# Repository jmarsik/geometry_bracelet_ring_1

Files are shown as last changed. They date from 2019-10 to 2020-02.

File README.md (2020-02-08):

# Geometry bracelet or ring #1

OpenSCAD project that creates various customizable bracelet or ring models. You can play with a lot of parameters to archive the desired look of your bracelet (see picture).

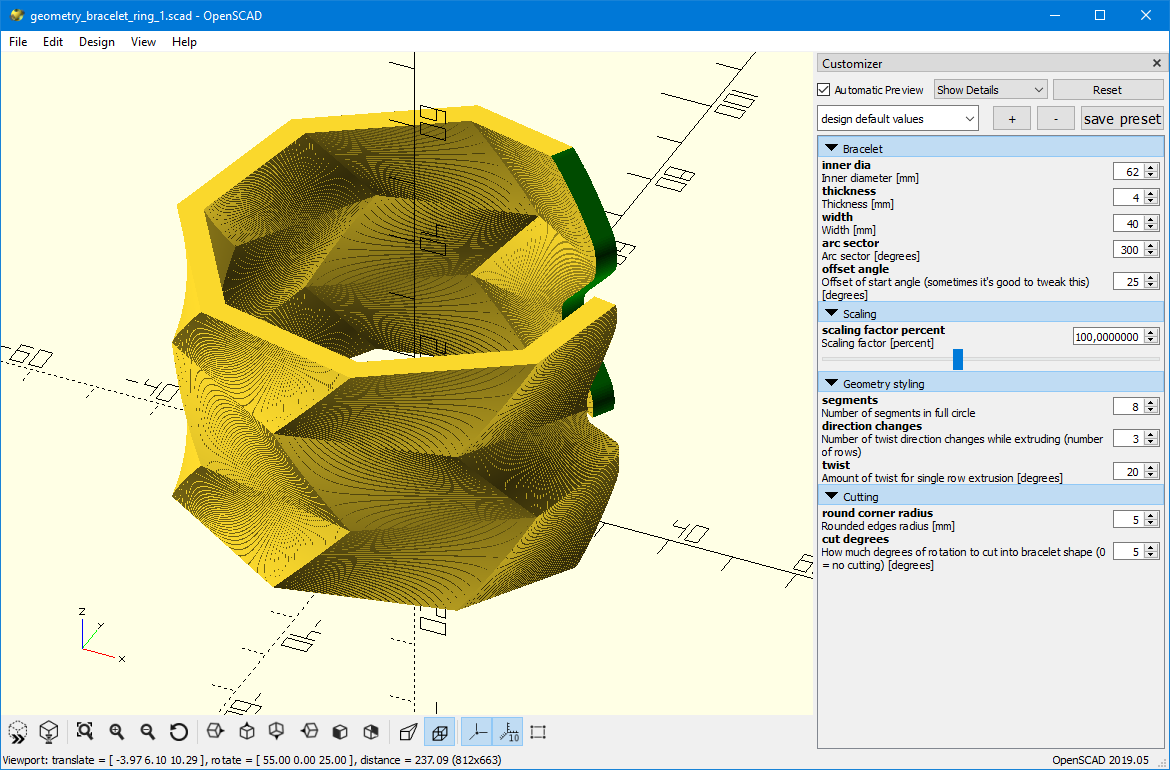
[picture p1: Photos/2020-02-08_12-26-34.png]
Bracelet customizer


There are also ready-made STL files for two bracelets and one ring, both with 8 segments, 3 directional changes and 20 degrees of twist for each directional change.

Check it out on [Thingiverse](https://www.thingiverse.com/thing:4150252) with [online customizer](https://www.thingiverse.com/apps/customizer/run?thing_id=4150252) and on [PrusaPrinters](https://www.prusaprinters.org/prints/20858-geometry-bracelet-ring)!

## Print settings

Print with some (semi)transparent PETG filament with following settings:

* without infill
* 2 perimeters
* 5 top and bottom solid layers

## Filament tips

I have tested following filaments, both bracelets and rings made from them look great and they are also __UV reactive__ (glowing in UV light)!

* [Prusament PETG Neon Green](https://amzn.to/2S9jRz5)
* [Prusament PLA Mr. Pink](https://shop.prusa3d.com/en/prusament/718-prusament-pla-ms-pink-1kg.html)

There are other UV reactive filaments listed on Amazon, some tips (not tested):

* [MG Chemicals Fluorescent Red / Hot Pink PLA](https://amzn.to/2Uy1OEe)
* [Gizmo Dorks Fluorescent Yellow PLA](https://amzn.to/39fn1Hl)
* [Gizmo Dorks Fluorescent Blue PLA](https://amzn.to/2OA5rWn)

Disclaimer: Some of the links above are affiliate links.

## Requirements

If you want to play with the design in OpenSCAD or you want to modify the code and contribute, you will need:

* [OpenSCAD](https://www.openscad.org/) version 2019.05 or later
* [Polyround library](https://github.com/Irev-Dev/Round-Anything)

For Thingiverse online customizer the SCAD file is slightly modified - the library file is included directly in the main file (no use statement) and let statements are expanded, because Thingiverse probably uses older version of OpenSCAD engine.

## Example prints

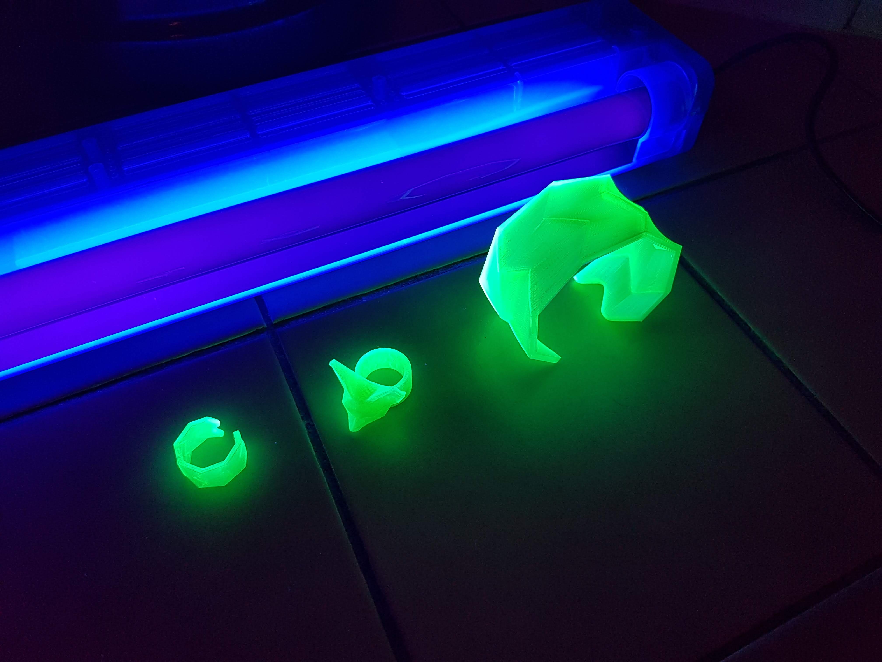
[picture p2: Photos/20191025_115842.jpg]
Example print 1

Example print 2
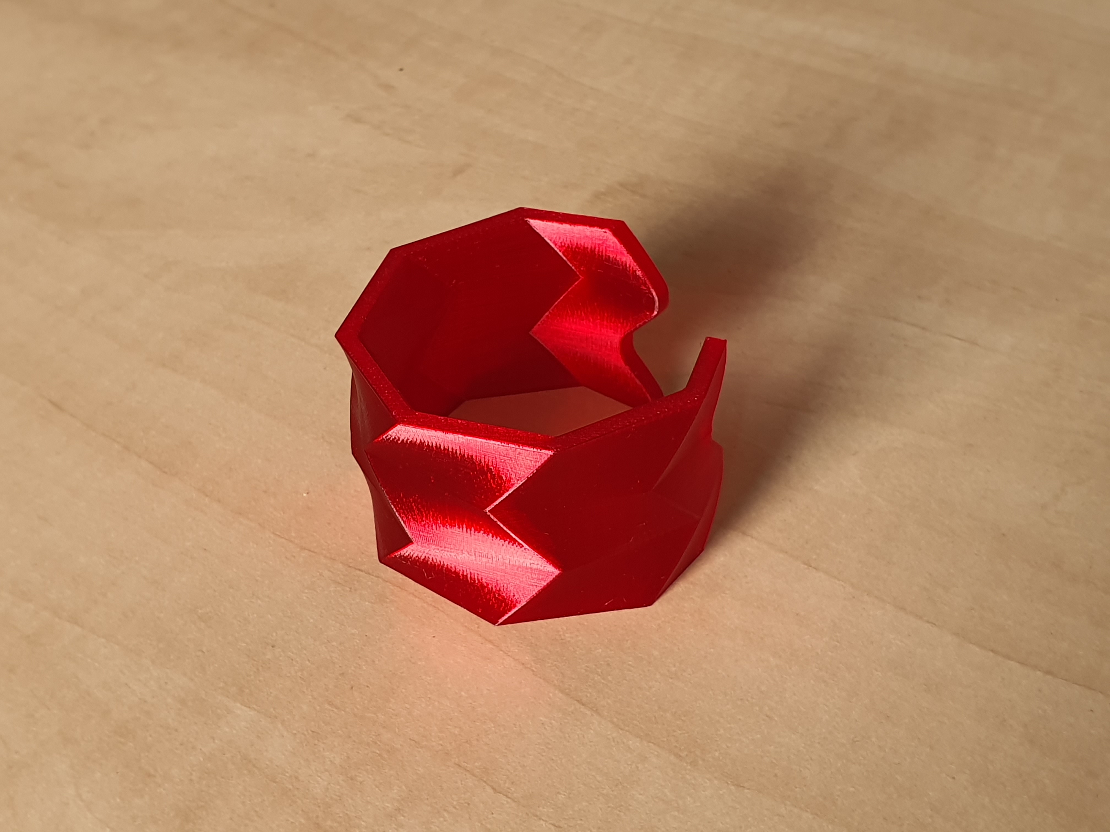
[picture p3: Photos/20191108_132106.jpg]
Example print 3

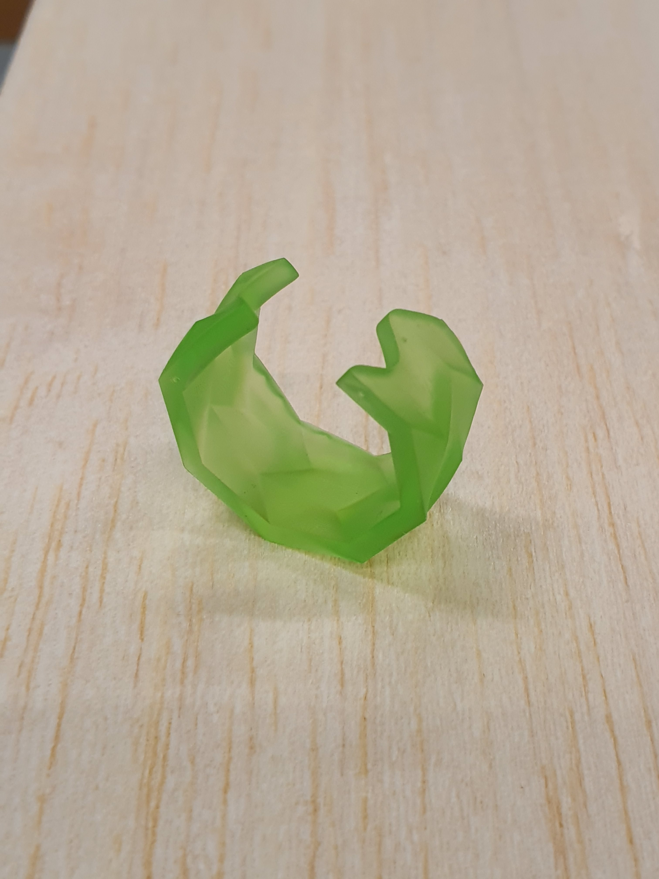
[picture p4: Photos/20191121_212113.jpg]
Example print 4


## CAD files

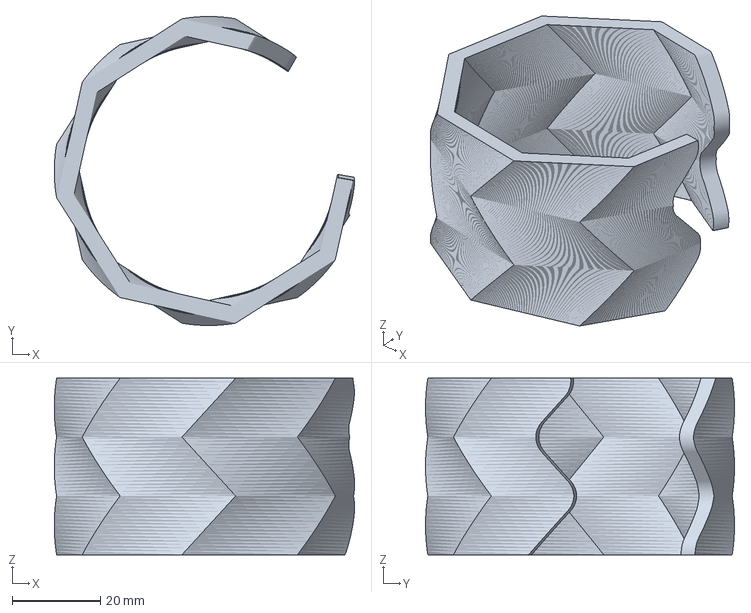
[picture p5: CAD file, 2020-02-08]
Examples/geometry_bracelet_ring_1-62mmID_4mmT_40mmW_3x20deg_300deg.3mf
68.1 x 70.0 x 40.0 mm

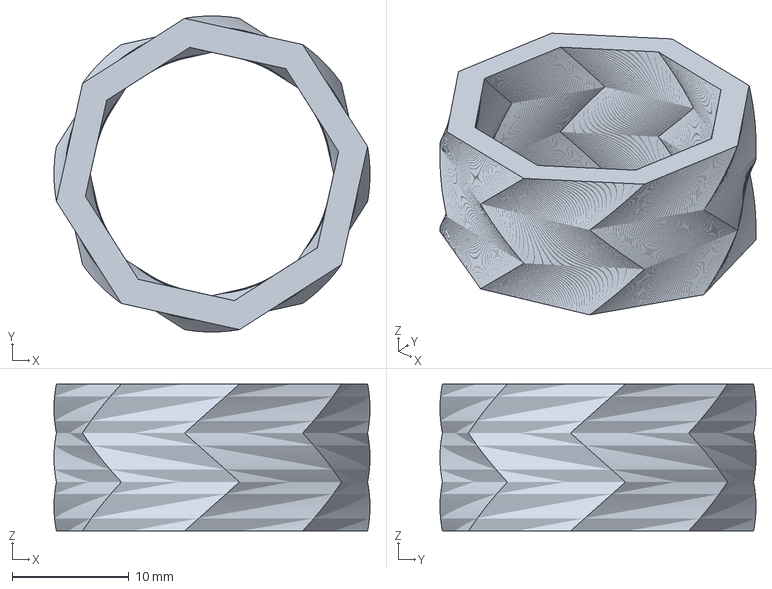
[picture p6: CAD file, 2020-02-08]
Examples/geometry_bracelet_ring_1-70mmID_8mmT_40mmW_3x20deg_360deg_31scale.3mf
27.1 x 27.1 x 12.6 mm

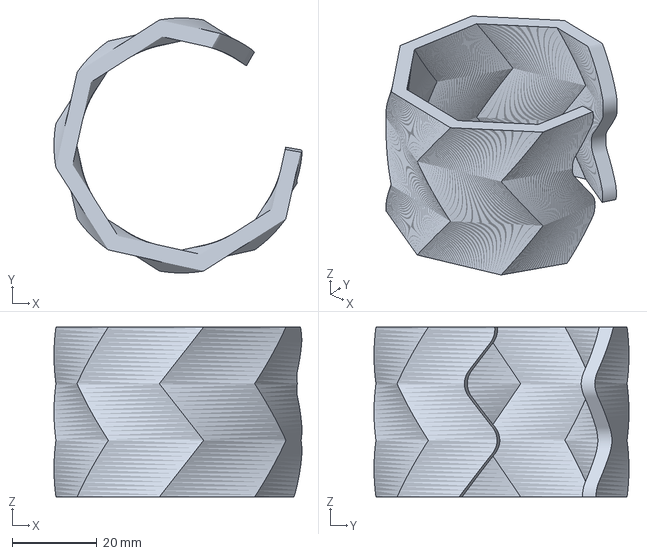
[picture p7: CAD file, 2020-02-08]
Examples/geometry_bracelet_ring_1-52mmID_4mmT_40mmW_3x20deg_300deg.3mf
58.4 x 60.0 x 40.0 mm

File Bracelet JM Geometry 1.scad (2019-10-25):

// Geometry bracelet
// Author: Jakub Marsik (jmarsik@fullvent.cz)

/* [Bracelet] */
// Inner diameter [mm]
inner_dia = 62;
// Thickness [mm]
thickness = 4;
// Width [mm]
width = 40;
// Arc sector [degrees]
arc_sector = 300;
// Offset of start angle (sometimes it's good to tweak this) [degrees]
offset_angle = 25;

/* [Geometry styling] */
// Number of segments in full circle
segments = 8;
// Number of twist direction changes while extruding (number of rows)
direction_changes = 3;
// Amount of twist for single row extrusion [degrees]
twist = 20;

/* [Cutting] */
// Rounded edges radius [mm]
round_corner_radius = 5;
// How much degrees of rotation to cut into bracelet shape (0 = no cutting) [degrees]
cut_degrees = 5;

// =========================================

/* [Hidden] */

// outer radius
r1 = (inner_dia + 2 * thickness) / 2;
echo(r1);
row_width = width / direction_changes;

// arc sector to optimal start and end angle to balance starting and ending segment part size
segment_sector = 360 / segments;
full_segments_sector = segment_sector * floor(arc_sector / segment_sector);
echo(full_segments_sector);
part_segments_sector = arc_sector - full_segments_sector;
start_angle = segment_sector - part_segments_sector / 2 + offset_angle;
end_angle = start_angle + arc_sector;
echo(str("Start angle: ", start_angle, "; end angle: ", end_angle));

cutting_tool_extrude = thickness * 3;
cutting_tool_extend_x_by = 15;

// cutting tool top and bottom modification factors for different number of twist direction changes (odd or even number) and different initial twist direction (positive or negative)
start_cutting_tool_top_factor = (direction_changes % 2 == 0 ? (twist > 0 ? -2 : 5) : (twist > 0 ? 5 : -2));
start_cutting_tool_bottom_factor = (twist > 0 ? -2 : 5);
end_cutting_tool_top_factor = (direction_changes % 2 == 0 ? (twist > 0 ? 5 : -2) : (twist > 0 ? -2 : 5));
end_cutting_tool_bottom_factor = (twist > 0 ? 5 : -2);

// =========================================

// validations
assert(inner_dia > 10 && inner_dia < 250, "Inner diameter out of range");
assert(thickness > 0 && thickness < inner_dia / 4, "Thickness out of range");
assert(width > 0 && width < 500, "Width out of range");
assert(arc_sector > 45 && arc_sector <= 360, "Arc sector out of range");
assert(segments > 0 && segments < 128, "Number of segments out of range");
assert(direction_changes >= 0 && direction_changes < 128, "Number of twist direction changes out of range");
assert(twist > -360 && twist < 360, "Twist out of range");
assert(round_corner_radius >= 0 && round_corner_radius < row_width, "Round corner radius out of range");
assert(cut_degrees >= 0 && cut_degrees < 12, "Cut degrees out of range");

// =========================================

// https://github.com/Irev-Dev/Round-Anything
use <polyround.scad>;

function len3(v) = len(v) > 1 ? sqrt(addl([for(i = [0 : len(v) - 1]) pow(v[i], 2)])) : len(v) == 1 ? v[0] : v; 
function addl(l, c = 0) = len(l) -1 > c ? l[c] + addl(l, c + 1) : l[c];

function point_on_circle(r, a) = [r * cos(a), r * sin(a), 0];

module regular_polygon(order = 4, r) {
    angles = [ for (i = [0:order - 1]) i * (360 / order) ];
    coords = [ for (th = angles) [r * cos(th), r * sin(th)] ];
    polygon(coords);
}
 
module sector(angle1, angle2, r) {
    points = [
        for(a = [angle1 : 1 : angle2]) [r * cos(a), r * sin(a)]
    ];
    polygon(concat([[0, 0]], points));
}

module raw_bracelet() { 
    for (step = [0 : direction_changes - 1])
        let (dir = step % 2 == 0 ? -1 : 1) {
        translate([0, 0, step * row_width]) {
            rotate(twist / 2 * dir) {
                linear_extrude(width / direction_changes, center = false, twist = twist * dir, slices = 100, convexity = 10) {
                    intersection() {
                        difference() {
                            regular_polygon(segments, r = r1);
                            regular_polygon(segments, r = r1 - thickness);
                        }
                        sector(start_angle, end_angle, r1 + 5);
                    }
                }
            }
        }
    }
}

module cutting_tool(extend_x_by, top_factor, bottom_factor) {
    single_dir_change_len = len3(point_on_circle(r1, 0) - point_on_circle(r1, twist / 2)) * sign(twist);
    // zigzag polyline covering all the rows of the bracelet
    points1 = [ for (step = [0 : direction_changes]) let (dir = step % 2 == 0 ? -1 : 1) [dir * single_dir_change_len, step * row_width, round_corner_radius] ];
    // extension (continuation of the shape) - bottom and top
    points1b = concat([[bottom_factor * points1[0][0], -1 * row_width, round_corner_radius]], points1, [[top_factor * points1[len(points1) - 1][0], (direction_changes + 1) * row_width, round_corner_radius]]);
    // another polyline a little bit shifted from the previous one
    points2 = [ for (i = [len(points1b) - 1 : -1 : 0]) [points1b[i][0] + extend_x_by, points1b[i][1], points1b[i][2]] ];
    points = concat(points1b, points2);
    echo(points);

    // polygon from all the points, with rounded corners
    polygon(polyRound(points, fn = 20));
}

module cutting_tool_rotated(angle, extend_x_by, top_factor, bottom_factor) {
    translate(point_on_circle(r1 - cutting_tool_extrude / 2 - thickness / 2, angle))
    rotate(90 + angle, [0, 0, 1])
    rotate(90, [1, 0, 0])
    linear_extrude(cutting_tool_extrude, convexity = 5)
    cutting_tool(extend_x_by, top_factor, bottom_factor);
}

difference() {
    raw_bracelet();
    
    if (cut_degrees > 0) { color("green") cutting_tool_rotated(start_angle + cut_degrees, -cutting_tool_extend_x_by, start_cutting_tool_top_factor, start_cutting_tool_bottom_factor); } else {}
    
    if (cut_degrees > 0) { color("red") cutting_tool_rotated(end_angle - cut_degrees, +cutting_tool_extend_x_by, end_cutting_tool_top_factor, end_cutting_tool_bottom_factor); } else {}
}

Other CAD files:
geometry_bracelet_ring_1.scad
Examples/geometry_bracelet_ring_1-52mmID_4mmT_40mmW_3x20deg_300deg.stl
Examples/geometry_bracelet_ring_1-62mmID_4mmT_40mmW_3x20deg_300deg.stl
Examples/geometry_bracelet_ring_1-70mmID_8mmT_40mmW_3x20deg_360deg_31scale.stl

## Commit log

2019-10-25 first version of geometry bracelet openscad definition, manual tuning via parameters in code
    [Bracelet JM Geometry 1.scad]
2019-10-25 much better customizer support, added automatic start / end angle calculations, added automatic top/bottom cutting tools modification factors calculation (depends on number of direction changes and s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
    [Bracelet JM Geometry 1.scad]
2020-02-07 added scaling factor and renamed main file
    [geometry_bracelet_ring_1.scad]
2020-02-07 demonstration photos and STL files
    [geometry_bracelet_ring_1-52mmID_4mmT_40mmW_3x20deg_300deg.stl, geometry_bracelet_ring_1-62mmID_4mmT_40mmW_3x20deg_300deg.stl, geometry_bracelet_ring_1-70mmID_8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]
2020-02-08 pre-sliced example GCODE files, 3MF files for given STLs; link to PrusaPrinters; .gitattributes to stabilize line endings
    [geometry_bracelet_ring_1-52mmID_4mmT_40mmW_3x20deg_300deg.3mf, geometry_bracelet_ring_1-62mmID_4mmT_40mmW_3x20deg_300deg.3mf, geometry_bracelet_ring_1-70mmID_8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]
